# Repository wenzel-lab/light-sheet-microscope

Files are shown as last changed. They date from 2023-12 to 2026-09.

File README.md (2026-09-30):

# CLAVE Microscope

## **CLAVE:**  Cube-based Light-sheet Apparatus for Versatile 3D-imaging Experiments

<p align="centre">
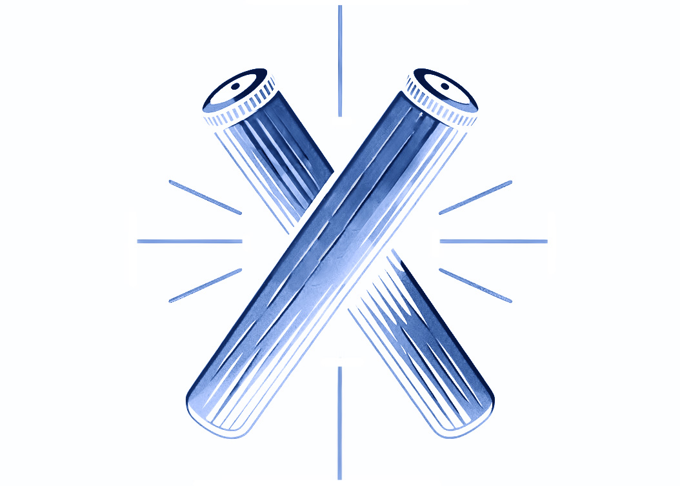
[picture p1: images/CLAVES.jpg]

</p>

Appropriate technology open source light sheet microscope design, for 3d imaging and high-throughput droplet cytometry. This is a modification of the OpenUC2 light sheet design - a project that can be explored by the [**website** ](https://openuc2.de/)and [**GitHub**](https://github.com/openUC2/UC2-GIT). This version has been developed as part of a [**crowd-funded project**](https://experiment.com/projects/developing-a-low-cost-high-sensitivity-solution-for-phage-viral-load-detection) on experiment.com by [Tobias Wenzel](https://librehub.github.io/people/tobias_wenzel/index.html) and [Benedict Diederich](https://openuc2.com/author/benedi/). In the Wenzel Lab, [Matías Hurtado](https://librehub.github.io/people/matias_hurtado/index.html) has also contributed to the design of several cubes, and the re-design of Inventor designs of [**UC2 cubes in OnShape.**](https://cad.onshape.com/documents/6ad90b1b9211810137d71b1d/w/b1b0cc05a0494bf4bc912f91/e/37e5ce9fc21af2a3e931ec46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)

### Work in progress:
A key aspect in terms of quality and cost of the light sheet microscope design is the laser-engine. With the open source laser we still dind't get an even-enough light sheet (until we improve a fiber vibration module), so we now oped for a second hand single 488nm colour coherent fiber laser that provides a very high quality gaussian beam. With this laser, the light sheet works great. We are also still in the process of trying alternative objectives and cameras, as well as finalising the sample holder and testing reference samples.

# Build your own:

<p align="centre">
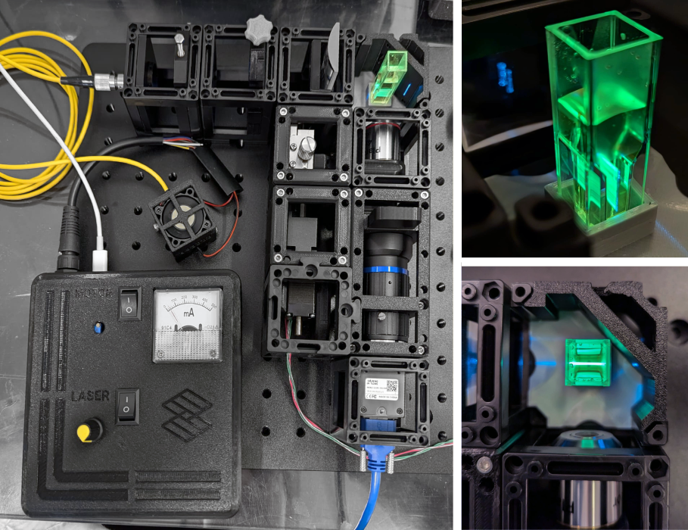
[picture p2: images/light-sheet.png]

</p>

<p align="centre">
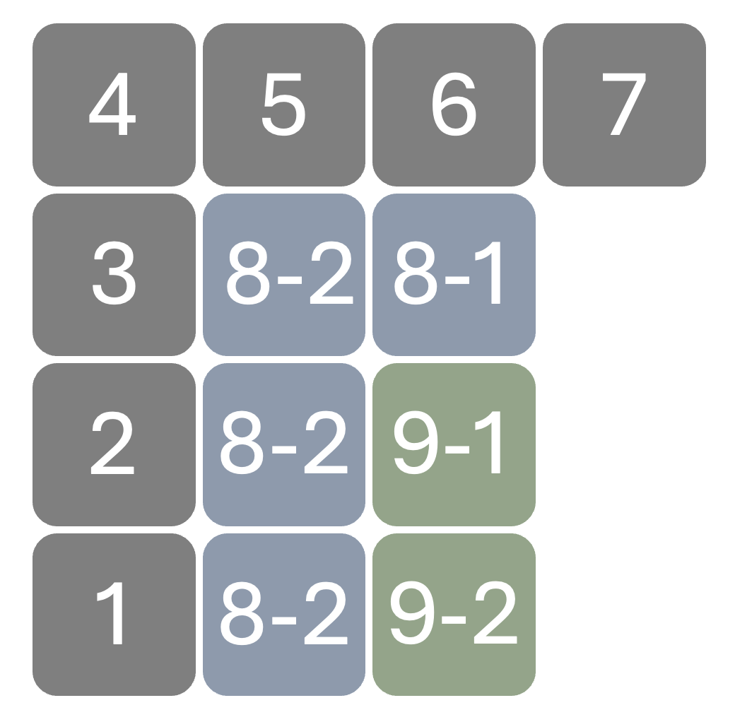
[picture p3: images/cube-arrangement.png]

</p>

<p align="centre">
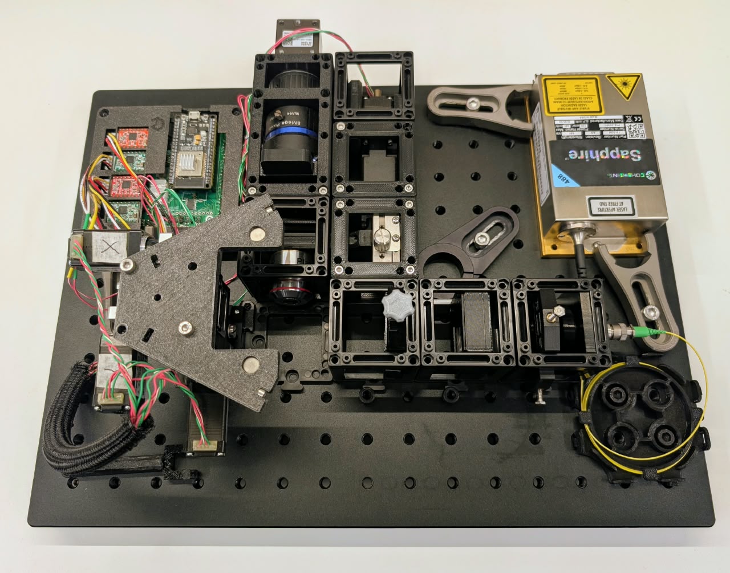
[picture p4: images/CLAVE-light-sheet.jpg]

</p>

## Navigation:

 * [Parts Gallery](gallery.md)

* [Prepare the pieces](Prepare.md)

* [Build your UC2](UC2files.md)

---

## Follow us:

  * [Twitter](https://twitter.com/WenzelLab), 
 * [YouTube](https://www.youtube.com/@librehub>), 
  * [LinkedIn](https://www.linkedin.com/company/92802424), 
*   [Instagram](https://www.instagram.com/wenzellab/), 
 *  [Printables](https://www.printables.com/@WenzelLab/models) &  [Thingiverse](https://www.thingiverse.com/libre-hub/designs)
* [LIBREhub website](https://librehub.github.io/),  
* [IIBM website](https://ingenieriabiologicaymedica.uc.cl/en/people/faculty/821-tobias-wenzel)

## Contribute:
This is an open project in the Wenzel Lab in Santiago, Chile. If you have any suggestions to improve it or add  additional functions make a pull-request or [open an issue](https://github.com/wenzel-lab/light-sheet-microscope/issues/new). For interactions in our team and with the community applies the [GOSH Code of Conduct](https://openhardware.science/gosh-2017/gosh-code-of-conduct/).

## License:
[CERN OHL 2W.](https://github.com/wenzel-lab/light-sheet-microscope/blob/main/LICENSE) This project is Open Source Hardware - please acknowledge us when using the hardware or sharing modifications.

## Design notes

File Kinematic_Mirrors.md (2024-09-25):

#Kinematic Mounts

Cube insert

{{BOM}}

[M3x20mm screw]: parts/mech/M3-20.md "{cat:mechanic}"
[M3 nut]: parts/mech/nuts.md "{cat:mechanic}"
[2.5mm Ball-end Allen key]: parts/tools/2.5mmBallEndAllenKey.md "{cat:tool}"
[Heat insert]: parts/mech/Hinsert.md "{cat:mechanic}"
[Round-Magnets]: parts/mech/magnets.md "{cat: mechanic}"

[Soldering iron]: parts/tools/soldiron.md "{cat:tool}"
[Tweezers]: parts/tools/tweezers.md "{cat:tool}"

[Knob]: models/Kinematic_Mirrors/Knob.stl "{previewpage}"
[Side-Kinematic-Mount-LIBREhub]: models/Kinematic_Mirrors/Side-Kinematic-Mount-LIBREhub.stl "{previewpage}"

[Diagonal-Kinematic-Mount-LIBREhub]:models/Kinematic_Mirrors/Diagonal-Kinematic-Mount-LIBREhub.stl "{previewpage}"
[Diagonal-Mirror-Surface-LIBREhub]:models/Kinematic_Mirrors/Diagonal-Mirror-Surface-LIBREhub.stl "{previewpage}"
[Side-Mirror-Surface-LIBREhub]:models/Kinematic_Mirrors/Side-Mirror-Surface-LIBREhub.stl "{previewpage}"

When using lasers, refractive elements for the beams are essential, even more the ones that can help control how and where exactly the light goes. In these models, the mirror can be calibrated from 3 knobs, 2 gold ones to move and a black one that is to be static

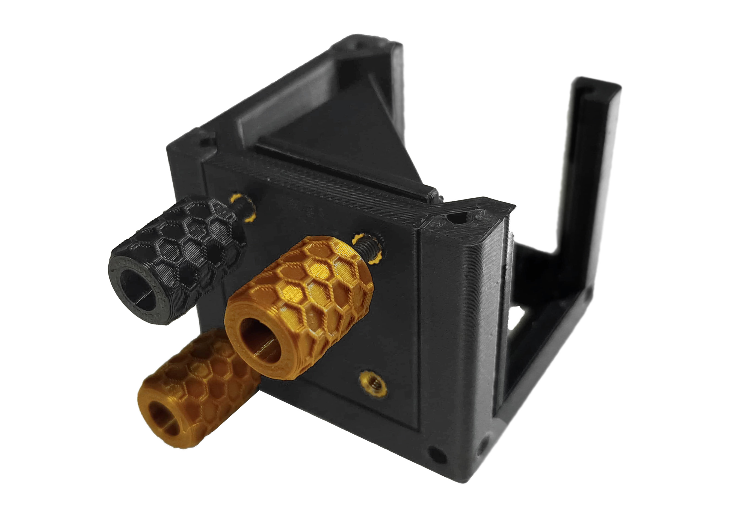
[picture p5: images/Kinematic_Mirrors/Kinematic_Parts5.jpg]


For this controlling system, we have two options depending on the user's needs.

- ## Diagonal Mirror:

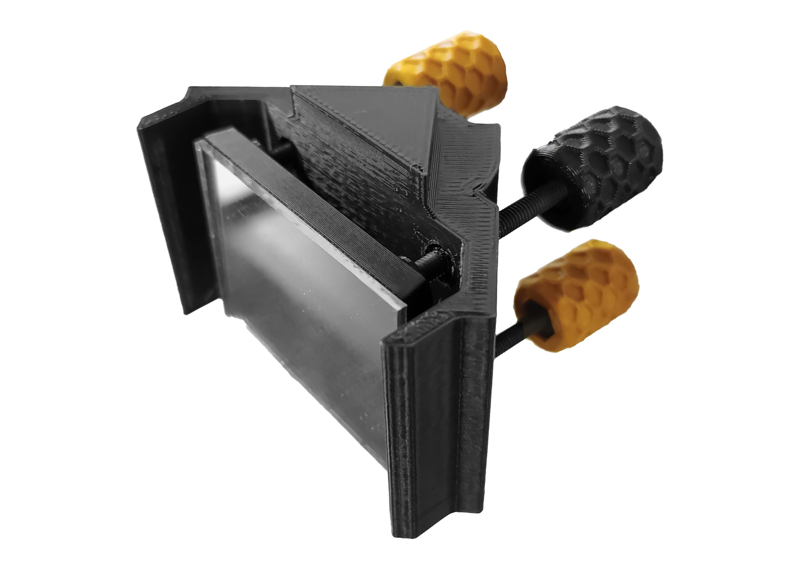
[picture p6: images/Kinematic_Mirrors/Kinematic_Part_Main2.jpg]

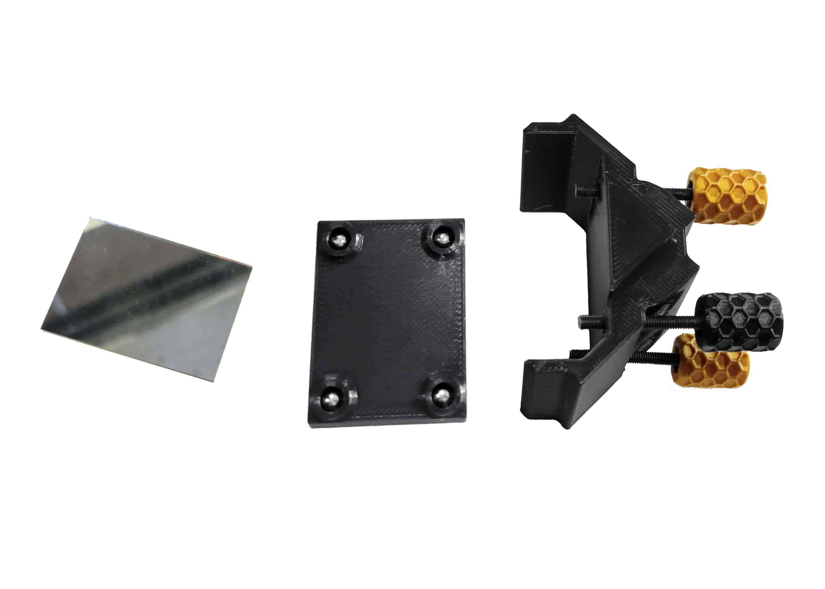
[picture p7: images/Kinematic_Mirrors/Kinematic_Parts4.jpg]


- ## Side Mirror:

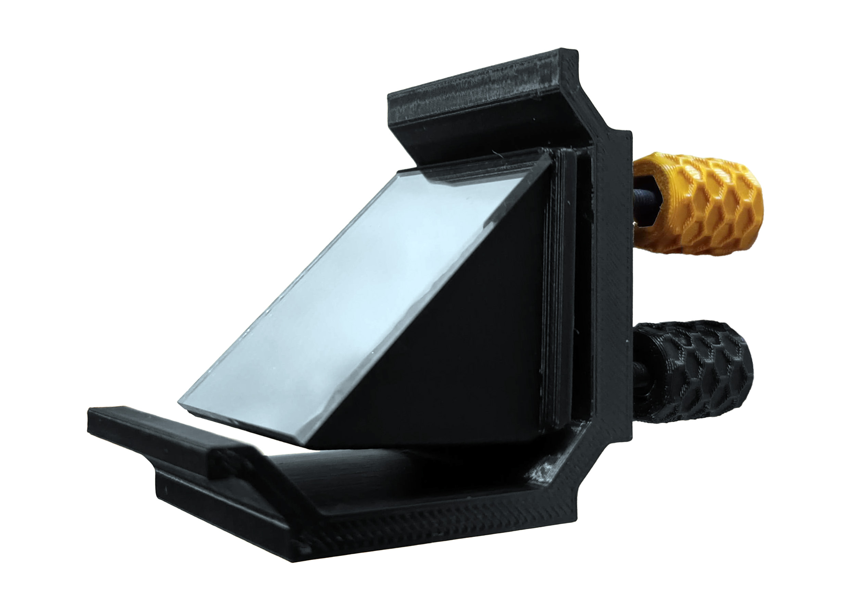
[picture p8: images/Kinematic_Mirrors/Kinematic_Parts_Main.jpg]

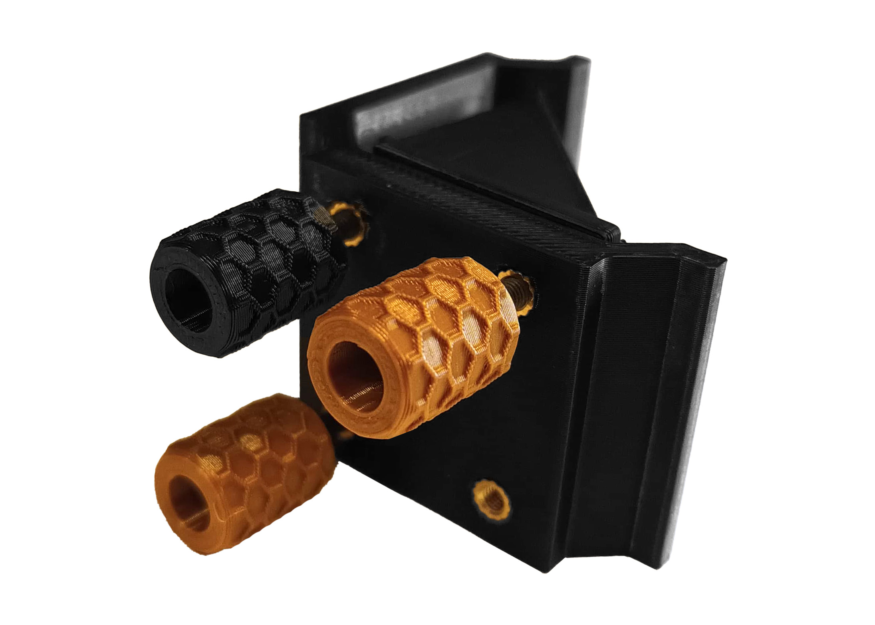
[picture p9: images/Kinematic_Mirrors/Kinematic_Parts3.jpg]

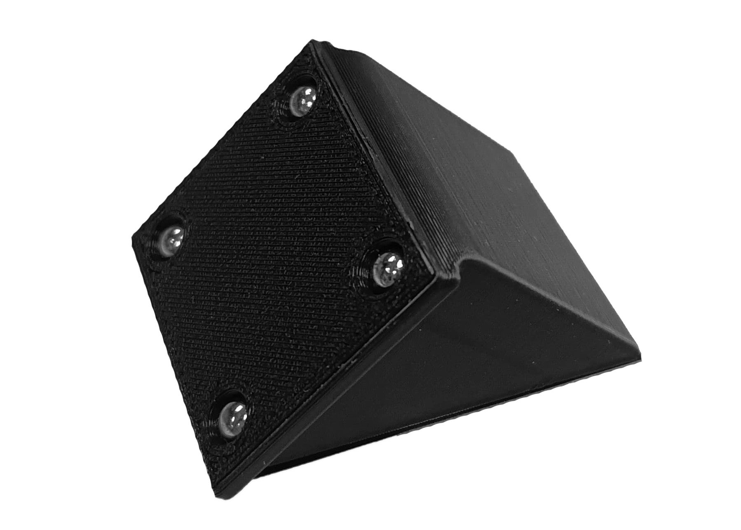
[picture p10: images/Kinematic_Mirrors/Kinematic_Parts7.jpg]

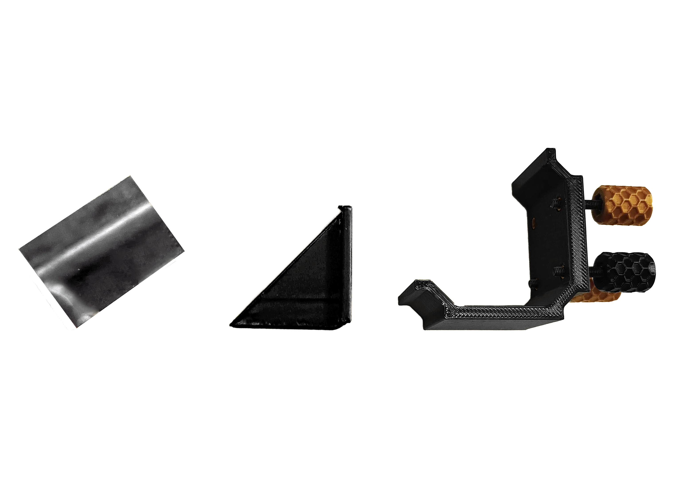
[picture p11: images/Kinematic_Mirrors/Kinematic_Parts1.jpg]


---

# Assemble the kinematic mounts:

## Knobs:{pagestep}

Place the [nut][M3 nut]{qty: 3} into the [knob][Knob]{qty: 3, cat:printedpart} and insert the [screw][M3x20mm screw]{qty: 3} tightly using the [Allen Key][2.5mm Ball-end Allen key]{qty:1}:



>? Please ensure that your screws are magnetic, as non-magnetic screws will not function properly with the magnets.

## Heat set inserts:{pagestep}

Use the [Soldering iron]{qty: 1} to place the [heat inserts][Heat insert]{qty: 3} into the [diagonal kinematic mount][Diagonal-Kinematic-Mount-LIBREhub]{qty: 1, cat:printedpart} or the [side kinematic mount][Side-Kinematic-Mount-LIBREhub]{qty: 1, cat:printedpart}, depending on the model you need.

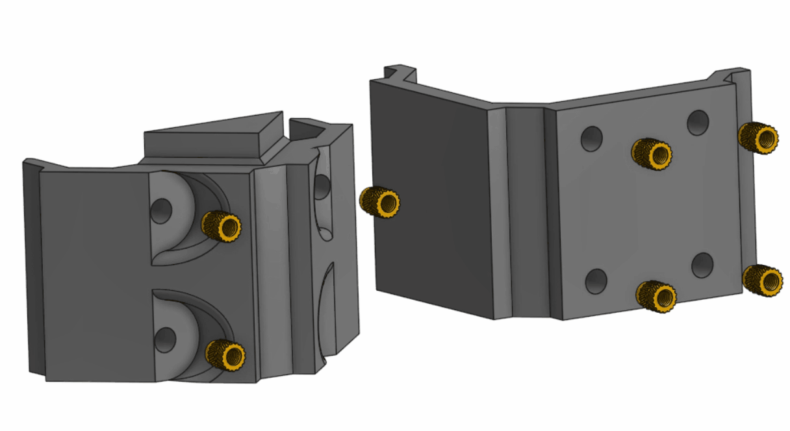
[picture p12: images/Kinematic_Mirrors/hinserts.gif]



## Place the magnets:{pagestep}

Place the [Round-Magnets]{qty: 4} in the [Diagonal-Mirror-Surface][Diagonal-Mirror-Surface-LIBREhub]{qty: 1, cat:printedpart} holes and press the flat side surface against the table to ensure that the surface stays completely flat. If you want to mount them for the [side kinematic mount][Side-Kinematic-Mount-LIBREhub], follow the same steps on the [Side-Mirror-Surface][Side-Mirror-Surface-LIBREhub]{qty: 1, cat:printedpart} but press the magnets into the piece and against the table so all the balls reach the opposite surface.

>! **Caution** 
>! The mirror surface must be flat so the mirror itself can be mounted

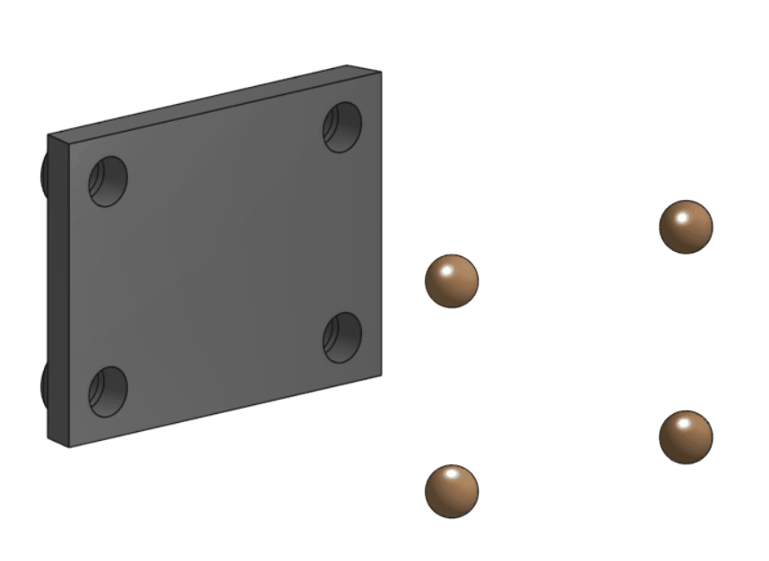
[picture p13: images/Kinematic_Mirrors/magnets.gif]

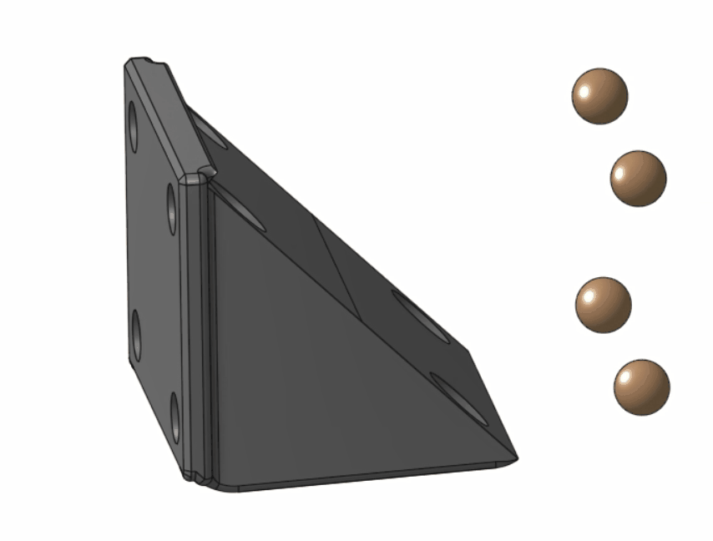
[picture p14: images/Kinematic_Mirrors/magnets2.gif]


## Mount the knobs:{pagestep}

Be sure to leave them all at the same approximate distance so they are easier to use later.



## Mount the Mirror:{pagestep}

1. Add some double-sided tape to the unprotected side of the mirror, peel off the plastic, and add it to the flat surface of the [Diagonal-Mirror-Surface][Diagonal-Mirror-Surface-LIBREhub]

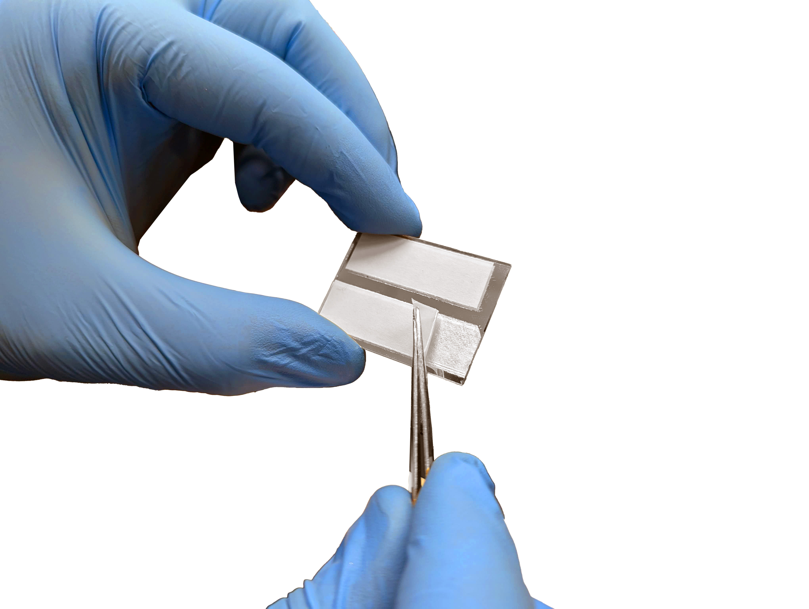
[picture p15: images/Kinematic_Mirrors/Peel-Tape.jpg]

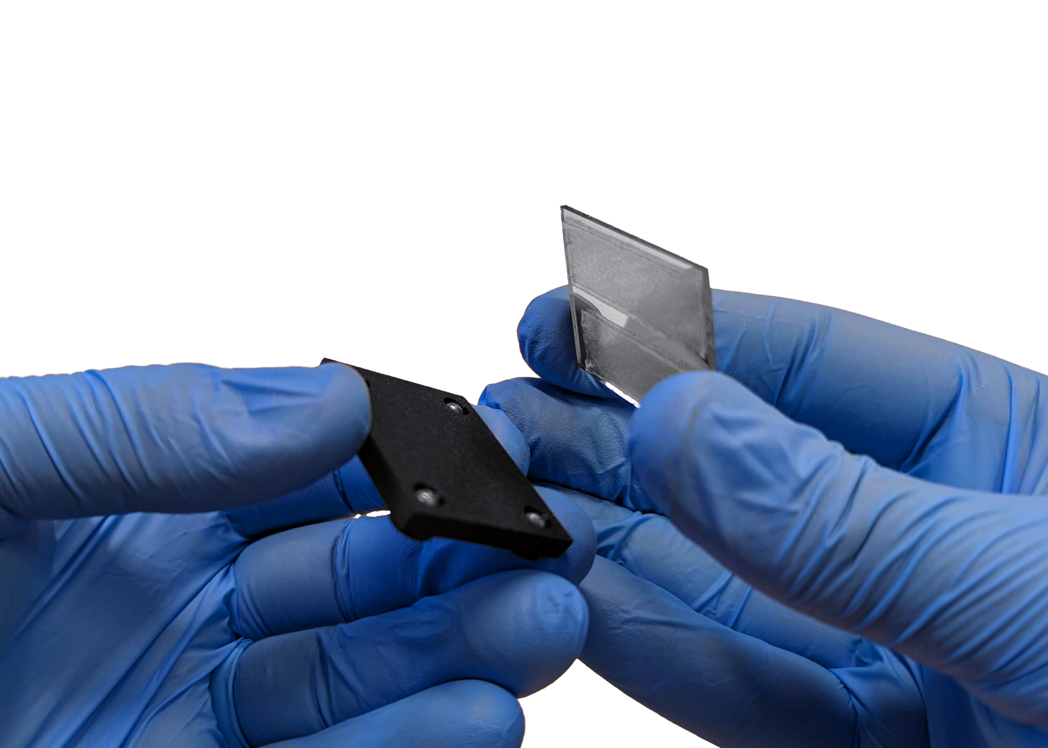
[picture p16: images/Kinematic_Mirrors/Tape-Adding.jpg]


2. Once added, peel off the protective plastic from the mirror with the [tweezers][Tweezers]{qty:1}

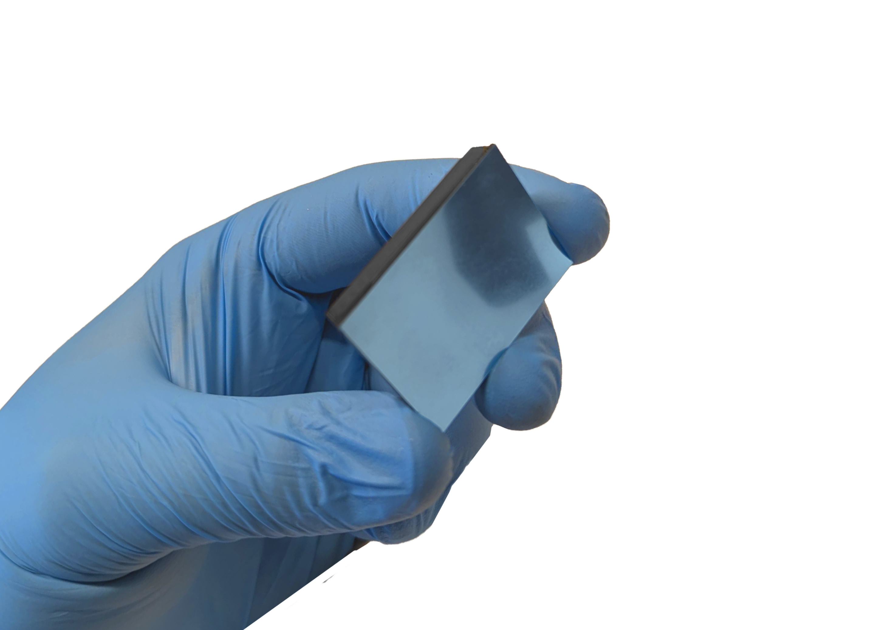
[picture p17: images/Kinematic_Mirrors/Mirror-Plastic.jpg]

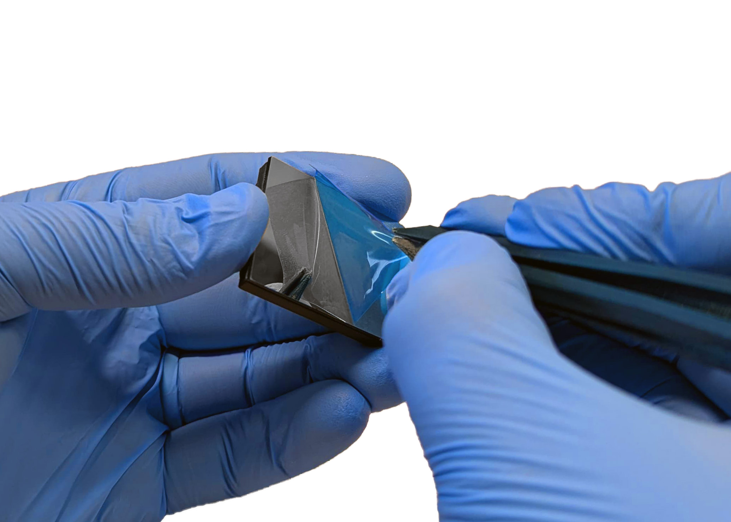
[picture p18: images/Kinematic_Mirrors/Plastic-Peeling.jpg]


3. Place the mirror holder onto the screw tips of the [kinematic mount][Diagonal-Kinematic-Mount-LIBREhub], the [magnets][Round-Magnets] will hold it in position.

>! **Caution** 
>! If the screw tips are not flat, the kinematic mirrors will not be as precise as they can be; therefore, it is necessary to [**sand them**](Sanding.md)

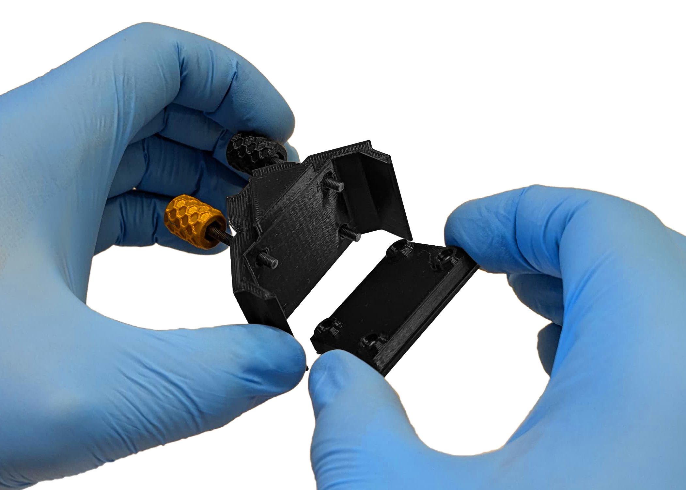
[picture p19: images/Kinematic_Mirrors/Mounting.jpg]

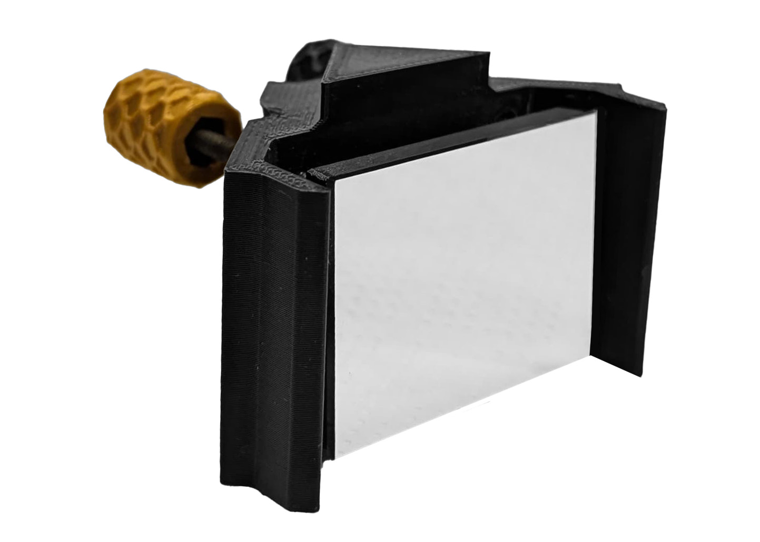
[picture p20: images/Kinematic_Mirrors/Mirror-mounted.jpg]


## Put it in a cube!:{pagestep}

Take one of your [UC2 cubes](UC2files.md) and place your assembled Kinematic Mirror in it. You can purchase the cube or 3D print it, either option works fine.

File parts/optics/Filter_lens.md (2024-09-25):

# Filter Lens
>!  This site is under construction.

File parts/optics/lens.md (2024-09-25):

# Lens

>!  This site is under construction.

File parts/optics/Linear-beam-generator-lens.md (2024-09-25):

---
PartData:
    Specs:
     Diameter: 9 mm
     Lens type: K9
     Material: Glass
     Degree: 5°
     _Supplier_: -[Aliexpress](www.aliexpress.com/item/1005005354365448.html)
---
# Linear Beam Generator Lens

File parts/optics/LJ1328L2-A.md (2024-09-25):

---
PartData:
    Specs:
        Length: 30 mm
        Width: 15 mm
        Thickness (center): 5.2 mm
        Radius: 10.3 mm
        Focal Length: 20.01 mm
        Antireflection Coating: 350-700 nm
        _Supplier_: -[Thorlabs](https://www.thorlabs.com/thorproduct.cfm?partnumber=LJ1328L2-A)
---
# LJ1328L2-A Lens

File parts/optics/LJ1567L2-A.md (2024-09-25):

---
PartData:
    Specs:
        Length: 60 mm
        Width: 30 mm
        Thickness (center): 5.2 mm
        Radius: 51.7 mm
        Focal Length: 100 mm
        Antireflection Coating: 350-700 nm
        _Supplier_: -[Thorlabs](https://www.thorlabs.com/thorproduct.cfm?partnumber=LJ1567L2-A)
---
# LJ1567L2-A Lens

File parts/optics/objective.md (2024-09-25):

# Objective
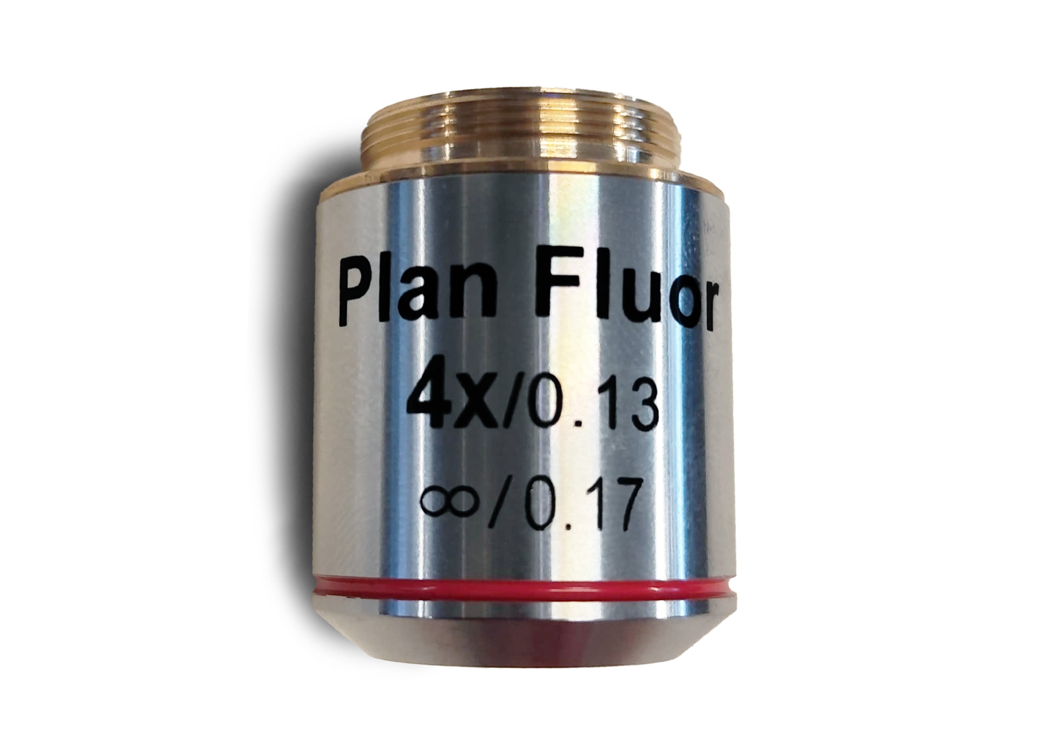
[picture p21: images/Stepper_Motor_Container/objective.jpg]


There are different types of objectives, depending on the experiment is which one you might need.

In this case, we are using a 4X/0.13 objective.

_Supplier_: [Thorlabs](https://www.thorlabs.com/thorproduct.cfm?partnumber=RMS4X-PF)

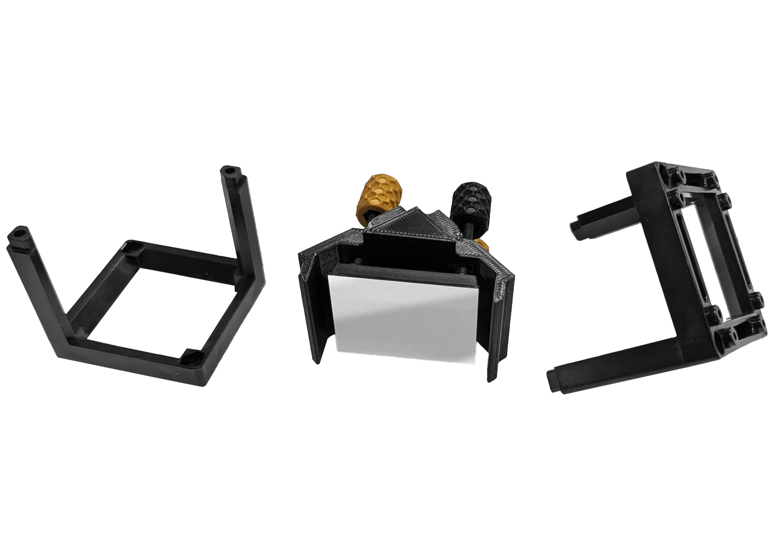
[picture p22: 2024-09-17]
images/Kinematic_Mirrors/Mirror-in-cube.jpg

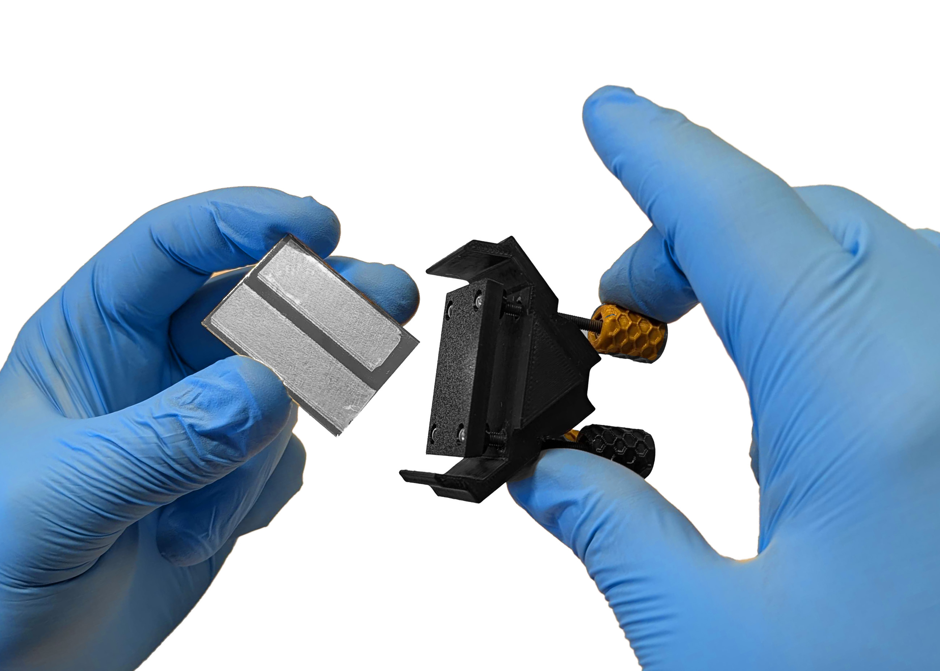
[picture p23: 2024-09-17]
images/Kinematic_Mirrors/Tape-Ready.jpg

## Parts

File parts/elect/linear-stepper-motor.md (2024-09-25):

#Stepper Motor



>!  This site is under construction.

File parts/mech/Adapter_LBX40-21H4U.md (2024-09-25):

# Adapter LBX40-21H4U

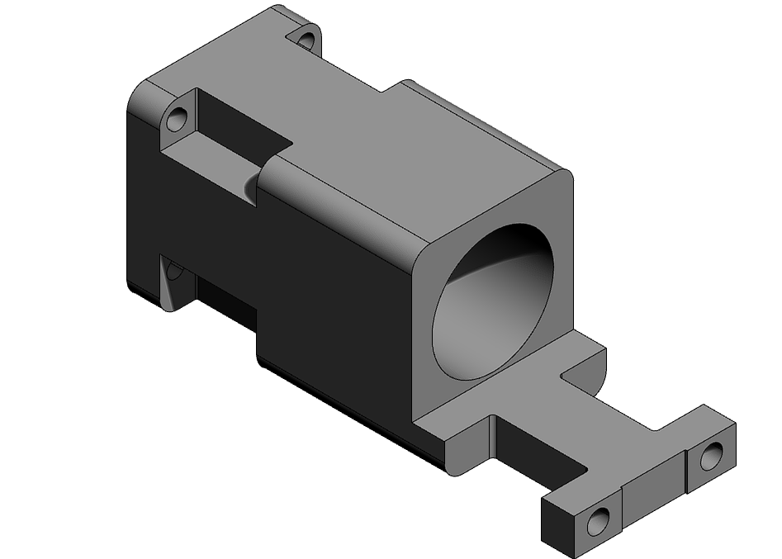
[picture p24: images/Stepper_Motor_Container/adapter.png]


You can dowload the STP file [here](../../models/Stepper_Motor_Container/adapter_LBX40_21H4U.stp), it is made to be CNC machinined.

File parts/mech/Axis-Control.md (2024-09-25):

# Axis Control

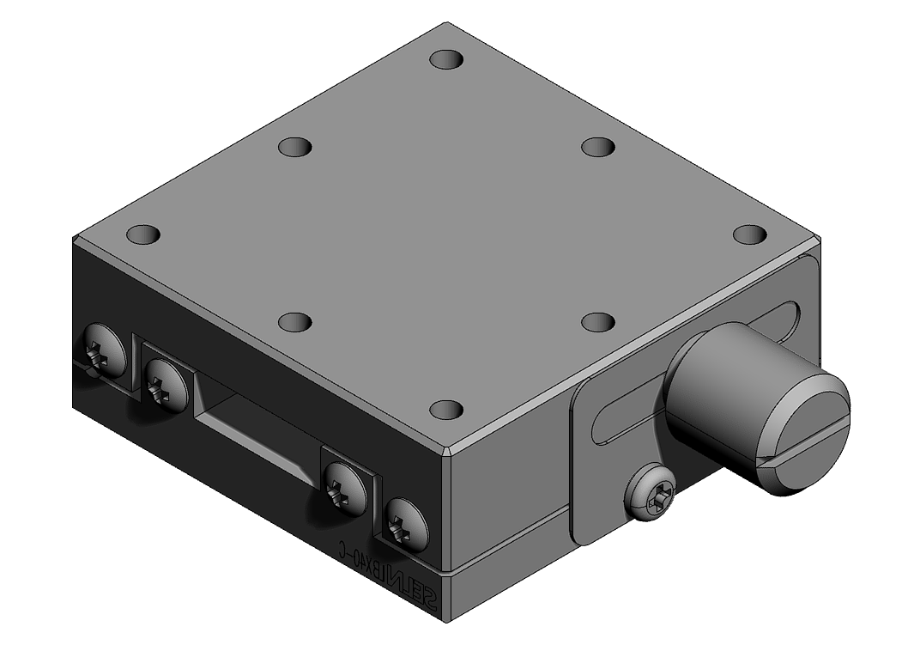
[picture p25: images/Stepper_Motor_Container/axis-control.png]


You can dowload the STP file [here](../../models/Stepper_Motor_Container/Axis-control.stp), it is made to be CNC machinined.

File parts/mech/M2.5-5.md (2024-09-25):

---
PartData:
    Specs:
        Type: M2.5
        Length: 5mm
        Material: Stainless steel
        Tool needed: HEX key
        Supplier:  -[Aliexpress](https://es.aliexpress.com/item/32810872544.html)

---
# Screw

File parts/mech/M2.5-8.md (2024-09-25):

---
PartData:
    Specs:
        Type: M2.5
        Length: 8 mm
        Material: Stainless steel
        Tool needed: HEX key
        Supplier:  -[Aliexpress](https://es.aliexpress.com/item/32810872544.html)
---
# Screw

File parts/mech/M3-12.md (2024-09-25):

---
PartData:
    Specs:
        Type: M3
        Length: 12mm
        Material: Stainless steel
        Tool needed: HEX key
        Supplier:  -[Aliexpress](https://es.aliexpress.com/item/32810872544.html)

---
# Screw

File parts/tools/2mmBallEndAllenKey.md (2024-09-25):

# 2 mm Ball-end Allen Key

Tool used to drive screws or bolts with hexagonal sockets. It has a metal shaft with a hexagonal cross-section. They come in different sizes for various applications.

It is important that the Allen key has a ball end:

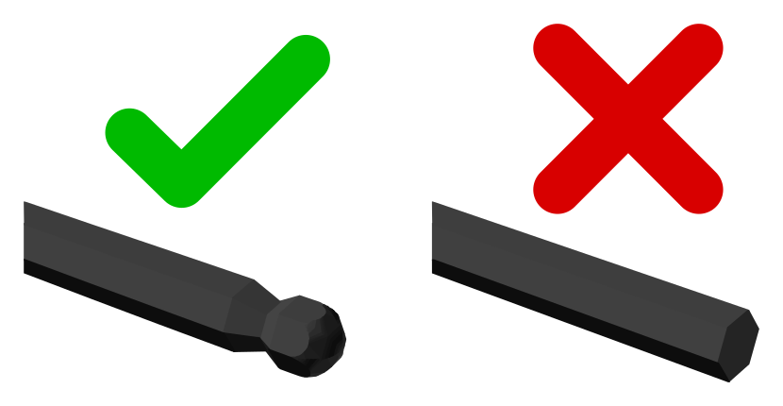
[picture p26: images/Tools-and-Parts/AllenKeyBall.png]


*Supplier:* [ferretería.cl](https://ferreteria.cl/ficha/5866/juego-de-llave-allen-larga-de-bola-metrico-9-pzs-tactix)

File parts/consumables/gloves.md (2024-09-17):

# Nitrile gloves

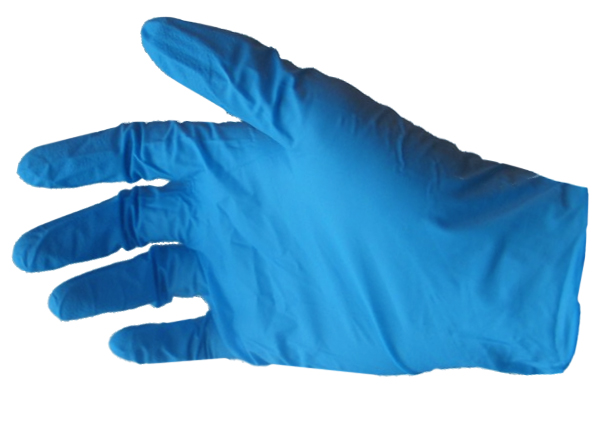
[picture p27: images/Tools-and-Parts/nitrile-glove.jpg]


They safeguard sensitive electronic components from contamination, oils, and static discharge.

These gloves prevent potential damage during assembly, repair, or handling of electronic devices.

*Supplier:* [bioquimica.cl](https://www.bioquimica.cl/guantes-de-nitrilo-sin-polvo-caja-100-un)

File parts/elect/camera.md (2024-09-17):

# High-Speed Camera

>!  This Site is under construction.

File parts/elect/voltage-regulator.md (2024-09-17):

# Voltage Regulator
It is used to control manually exactly how much electricity circulates. 



_Supplier:_ [AFEL](https://afel.cl/producto/regulador-de-voltaje-step-down-dc-dc-lm2596-con-voltimetro/)

This regulator has modifications documented [here](https://github.com/wenzel-lab/modular-microfluidics-workstation-controller)

>! In some models, the electronics of this can be exposed, be sure to cover them to avoid possible accidents.

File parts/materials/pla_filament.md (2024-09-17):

# PLA filament

The design has been tested using PLA filament only. PLA is the most common 3D printer filament. It is easy to use and has low part shrinkage. We have found that the lifetime of the parts is affected by the quality of the PLA filament, as such we recommend buying high quality filament and storing the filament in a dry sealed container before printing.

_Supplier:_ [Esun](https://www.esun3d.com/) or [Todo Toner](https://www.todotoner.cl/impresoras/impresoras-3d/filamentos/pla-plus-1kg-negro-esun)

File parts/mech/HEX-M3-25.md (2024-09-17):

---
PartData:
    Specs:
        Type: M3
        Length: 25mm
        Material: Stainless steel
        Tool needed: Spanner
        Supplier:  -[Aliexpress](https://aliexpress.com/item/32968601031.html)
---

# M3 HEX screw

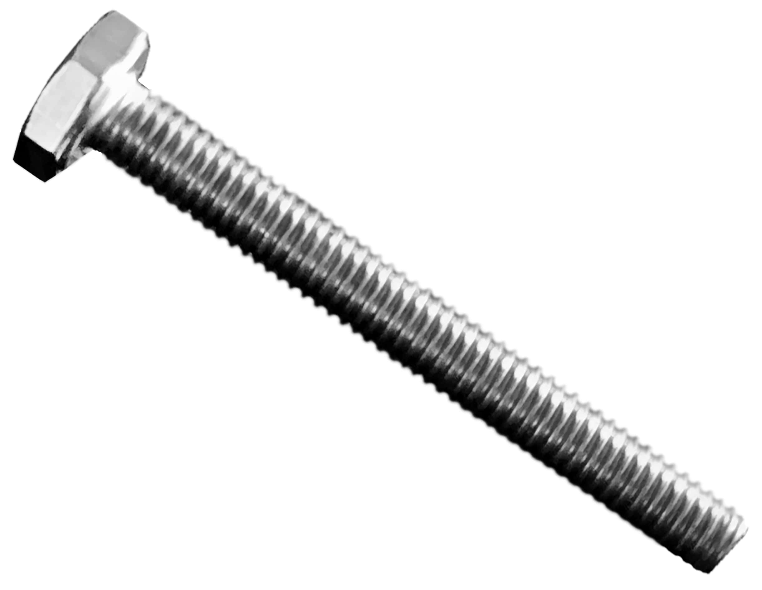
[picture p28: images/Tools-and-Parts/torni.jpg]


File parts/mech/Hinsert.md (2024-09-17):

---
PartData:
    Specs:
        Type: M3
        Diameter: 4mm aprox.
        Material: Brass
        Tool needed: Soldering iron
        Supplier: -[Aliexpress](https://es.aliexpress.com/item/1005005220632314.html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)

---
# Heat inserts

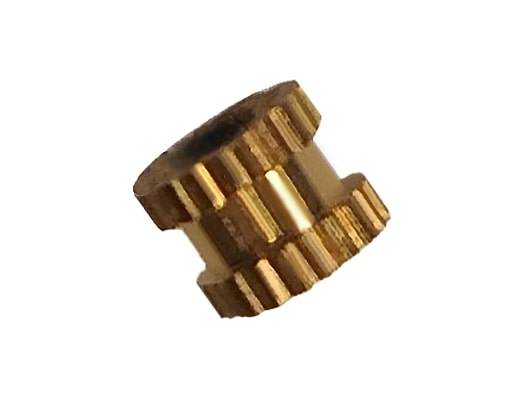
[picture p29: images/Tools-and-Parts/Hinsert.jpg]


Threaded insert used for creating secure connections in materials. Heat is applied to soften the material, allowing the insert to be pressed or screwed in. It provides a strong threaded connection in materials like plastic, acrylic and wood. Used in industries like electronics, automotive, and aerospace.

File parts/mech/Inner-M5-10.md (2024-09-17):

---
PartData:
    Specs:
        Type: M5
        Length: 10mm
        Material: Stainless steel
        Tool needed: HEX key
        Supplier:  -[Aliexpress](https://es.aliexpress.com/item/32810872544.html)
---
# Inner Screw

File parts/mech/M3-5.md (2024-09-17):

#screw

---
PartData:
    Specs:
        Type: M3
        Length: 5 mm
        Material: Stainless steel
        Tool needed: HEX key
        Supplier:  -[Aliexpress](https://es.aliexpress.com/item/32810872544.html)

---

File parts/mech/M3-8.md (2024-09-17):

---
PartData:
    Specs:
        Type: M3
        Length: 8mm
        Material: Stainless steel
        Tool needed: HEX key
        Supplier:  -[Aliexpress](https://es.aliexpress.com/item/32810872544.html)
---
# Screw

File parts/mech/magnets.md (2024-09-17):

---
PartData:
    Specs:
        Diameter: 5mm
        Supplier:  -[La casa del imán](https://www.lacasadeliman.cl/products/216-bolitas-magneticas)
---
# Round Magnets
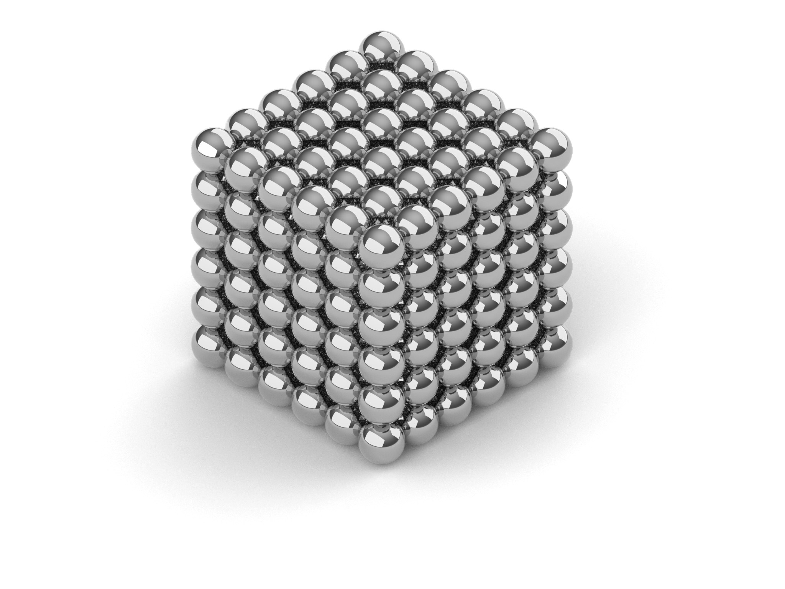
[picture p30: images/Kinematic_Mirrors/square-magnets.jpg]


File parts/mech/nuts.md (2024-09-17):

# Nut

Small hexagonal or square-shaped object with a threaded hole used to fasten objects together. It pairs with a screw.

*Supplier:* [Aliexpress](https://www.aliexpress.com/item/1005003780212966.html)

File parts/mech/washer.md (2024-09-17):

---
PartData:
    Specs:
        Type: M3
        Material: Stainless steel
        Supplier:  -[Pernos kim](https://pernos-kim.negocio.site/)

---
# Screw washer

* Small disk used with screws or bolts. It distributes the load and protects surfaces. It prevents damage and provides stability. Different materials and types are available for specific applications. It enhances the performance of the fastening system.

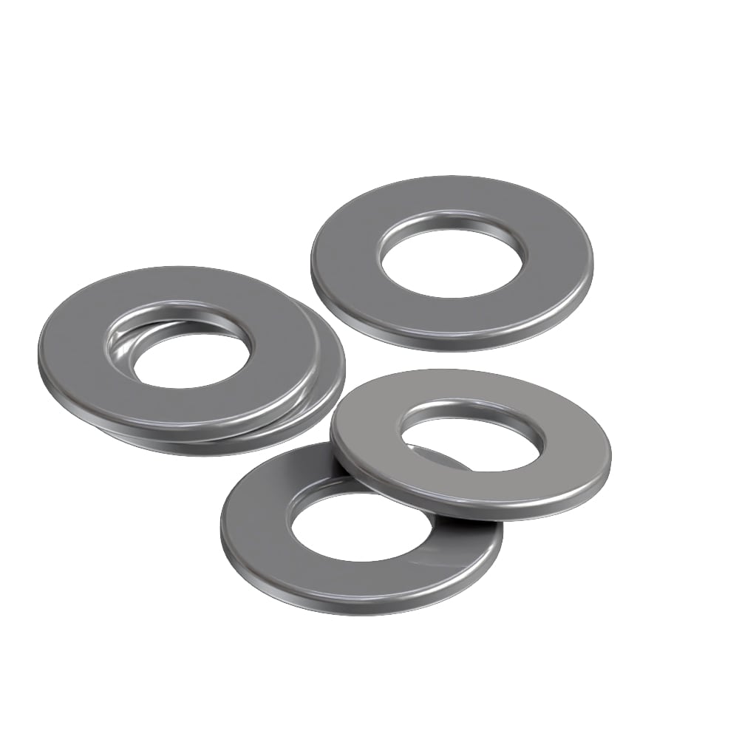
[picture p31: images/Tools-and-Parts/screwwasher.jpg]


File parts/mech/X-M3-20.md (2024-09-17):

---
PartData:
    Specs:
        Type: M3
        Length: 20 mm
        Material: Stainless steel
        Tool needed: screwdriver
        Supplier:  -[Aliexpress](https://es.aliexpress.com/item/32971605141.html)
---
# M3 X Screw



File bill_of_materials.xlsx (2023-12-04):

Category | Amount | Part | Shop | Price (€) | Comment | What we have | Quantity | URL/Source
External Parts | 1 | Cylindrical lens, comar | Thorolabs | 150 | f = 100mm H = 30 mm L = 32 mm | f = 8mm f = 50 mm f = 20 mm (2x) | 1 | Link (https://www.thorlabs.com/thorproduct.cfm?partnumber=LJ1567L1)
 | 1 | Camera, monochrome, CMOS | Daheng | 350 |  |  | 1 | Link (https://www.machinevisionkamera.de/USB3-Bildverarbeitungskamera-12.2MP-Monochrome-Sony-IMX226-MER2-1220-32U3M)
 | 1 | Focusing stage, micrometer, motorized (NEMA12) | China | 100 |  |  | 1 | Haoran
 | 1 | 10x objective, NA0.3, long-working distance | USA | 250 | 10x and NA 0.3 | 100x, NA1.25 100x NA1.4 20x NA0.5 12.5x NA? 10x NA0.25 is being used(yellow one) | 1 | Link (https://bolioptics.com/10x-infinity-corrected-plan-achromatic-microscope-objective-lens-bm05073332/)
 | 1 | XYZ stage, AliExpress, micrometer | China | 250 |  |  | 1 | Link (https://de.aliexpress.com/item/33013923564.html?gatewayAdapt=glo2deu)
 | 3 | Motor for stage | China | 80 |  |  | 3 | Link (https://eckstein-shop.de/PololuStepperMotorNEMA11Bipolar200StepsRev28C39732mm38V067APhase)
 | 1 | Tube lens | China | 200 | f = 100mm F3.5 | Lots of lenses does not have specifications | 1 | Link (https://www.berrybase.de/100mm-teleobjektiv-c-mount)
 | 1 | Fiber laser | China | 200 | ?? | https://www.thorlabs.com/thorproduct.cfm?partnumber=P1-460A-FC-5 This is the one that we have, dont know if it works | 1 | Haoran
 | 1 | Mirror | PGI | 5 | Simple small mirror | We have some thorlabs mirrors | 1 | Link (https://pgi-shop.de/vorderflaechen-glasspiegel-30-0-x-40-0-mm/)
 | 1 | 4x objective lens finite | China | 10 | 4x | 4x (x2) | 1 | Haoran
 | 1 | Fiber Collimator | China | 100 |  | Could we build it with lenses? | 1 | Haoran
 | 14 | Baseplates | openUC2 | 3 |  |  | 14
 | 8 | Cubes | openUC2 | 5 |  |  | 10
 | 1 | Solid baseplate (aluminium) | openUC2 | - |  |  | 1
 | 1 | Excitation filter (Thorlabs) | Thorolabs | 120 | 500 nm cut-on | 500 nm long pass (CORION) | 1 | Link (https://www.thorlabs.com/thorproduct.cfm?partnumber=FELH0500)
Inserts (3D printable?) | 1 | Fiber Collimator Mount | openUC2 | 5 |  |  | 1
 | 1 | Cylindrical Lens Mount | openUC2 | 5 |  |  | 1
 | 1 | 45° Mirror Mount (kinematic) | openUC2 | 25 |  |  | 1
 | 1 | RMS Lens Mount | openUC2 | 5 |  |  | 1
 | 1 | Sample mount (printed) | openUC2 | 30 |  |  | 1
 | 1 | Base for XYZ Stage | openUC2 | 2 |  |  | 1
 | 1 | Sample mount for XYZ Stage | openUC2 | 15 |  |  | 1
 | 1 | Holder for Z-stage motorized | openuc2 | 30 |  |  | 1
 | 1 | Holder for Tubelens | openUC2 | 10 |  |  | 1
 | 1 | Holder for UC2 Electronics | openUC2 | 30 |  |  | 1
Electronics | 1 | Electronics, Powersupply, Stepper driver | openUC2 | 100 |  |  | 1
 | 2 | USB cables (camera, micro) | Germany | 60 |  |  | 2
 | 1 | Playstation Controller | Germany | 50 |  |  | 1
 | 1 | Box + Foam insert | openUC2 | 100 |  |  | 1 | Link (https://www.contorion.de/p/stier-universal-outdoor-koffer-flugtauglich-lxbxh-418x317x151-mm-86520627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)
Labour & Shipping | - | Labour + Shipping | - | 500 |  |  | 1

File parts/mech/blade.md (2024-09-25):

# Razor Blades
>!  This site is under construction.

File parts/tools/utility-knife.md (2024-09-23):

# Utility knife / Box cutter

Any standard utility knife should work for simple jobs like removing a brim.

A retractable or fixed-blade utility knife should work. This is probably safer than a scalpel, but should still be used with caution! A Stanley Titan fixed blade knife is a high-quality option with replaceable blades that are fixed rather than retractable.



*Supplier:* [Sodimac](https://www.sodimac.cl/sodimac-cl/articulo/110284473/Cuchillo-cartonero-metal/110284475)

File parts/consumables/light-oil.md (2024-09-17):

# Light oil

A component that lubricates the mechanism to make it work more smoothly.



*Supplier:* [Sodimac](https://www.sodimac.cl/sodimac-cl/articulo/110368264/Lubricante-multiuso-para-auto-89-ml/110368269)

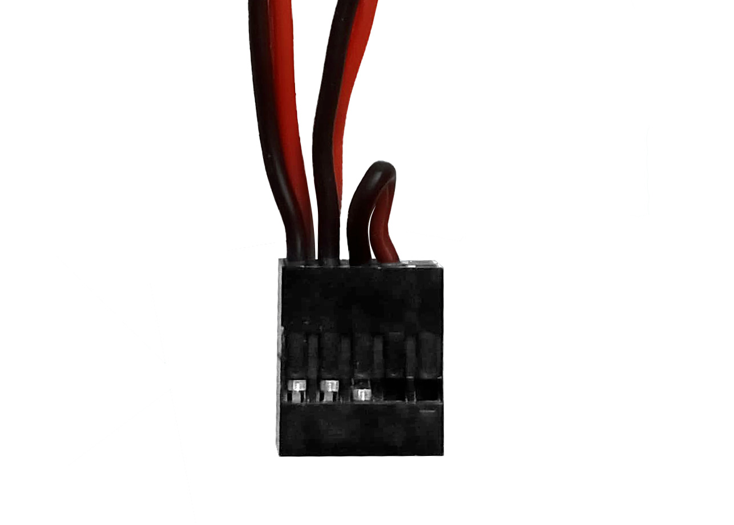
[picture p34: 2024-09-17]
images/Tools-and-Parts/strobe_cables.jpg

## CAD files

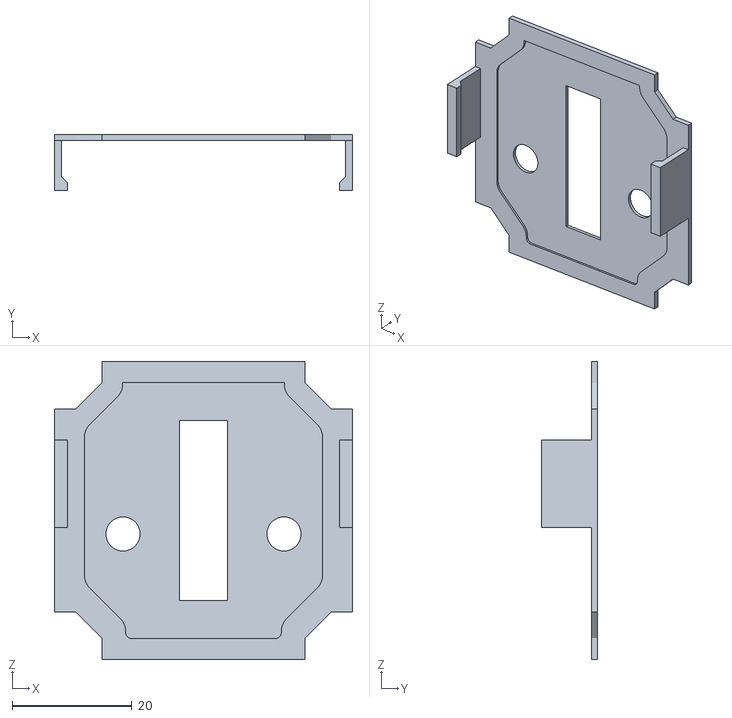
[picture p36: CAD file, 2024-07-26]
models/Adjustable_slit/Compliant_slit_insert_V2-cap_layer.stl
49.8 x 9.40 x 49.8

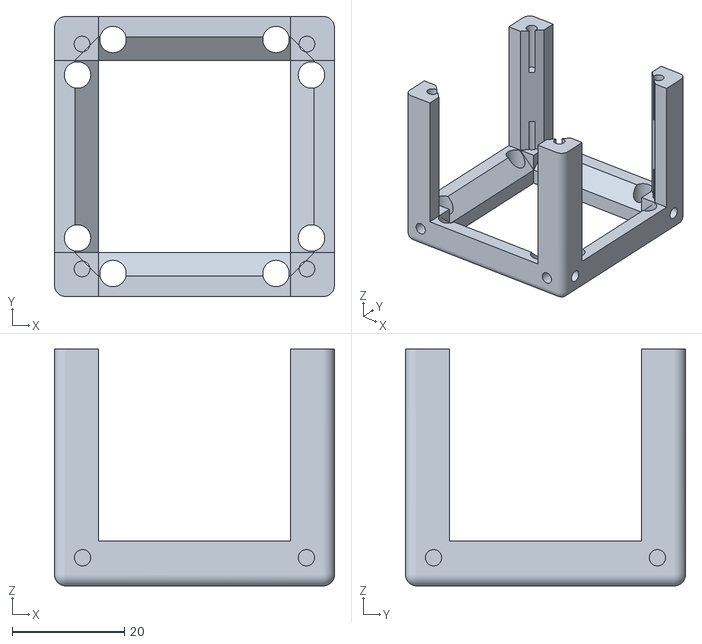
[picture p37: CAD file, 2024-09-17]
models/Base_Cube/Single_Base_Cube.stl
49.8 x 49.8 x 42.1

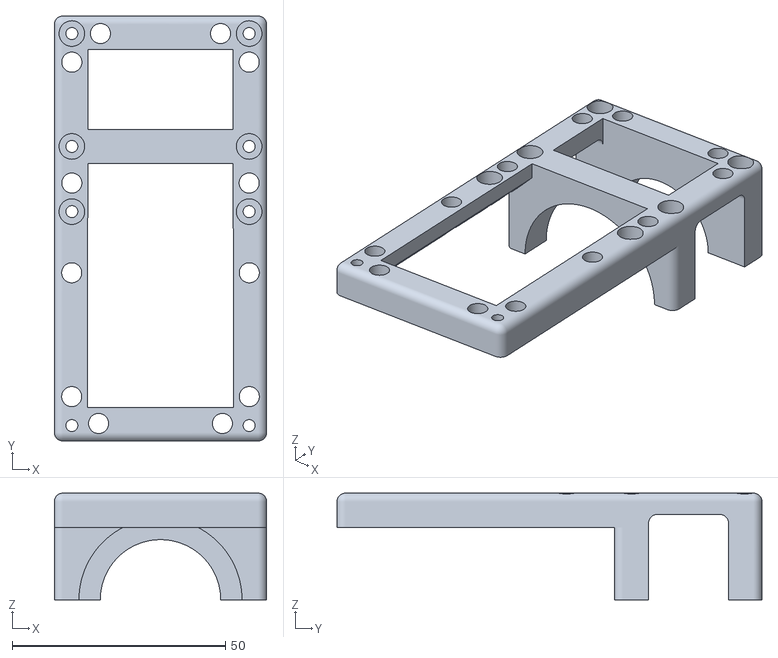
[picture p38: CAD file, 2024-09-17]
models/Double_Cube_Lens_Holder/LightSheet_Remake-Double_Cube_Lens_Holder_B.stl
49.8 x 99.6 x 25.0

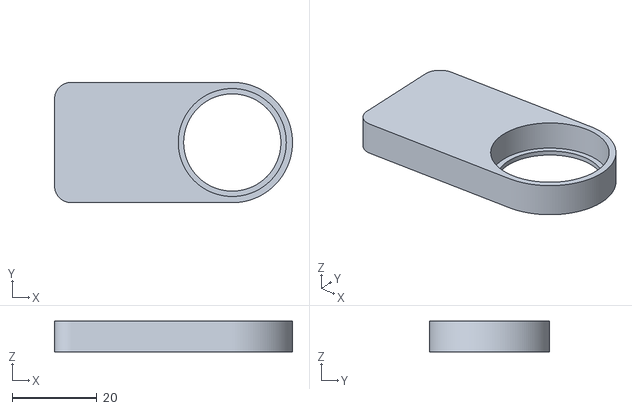
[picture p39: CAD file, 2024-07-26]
models/Filter_Holder/Filter-Slide-25-mm.stl
56.3 x 28.5 x 7.25

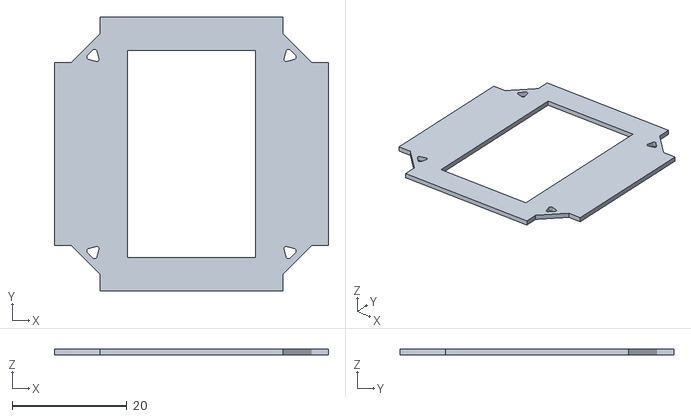
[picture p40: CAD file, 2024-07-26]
models/Flexure_cylindrical_lens_holder/Flexure_cylindrical_lens_holder-cyl-lens-holder-lid.stl
47.8 x 47.8 x 1.00

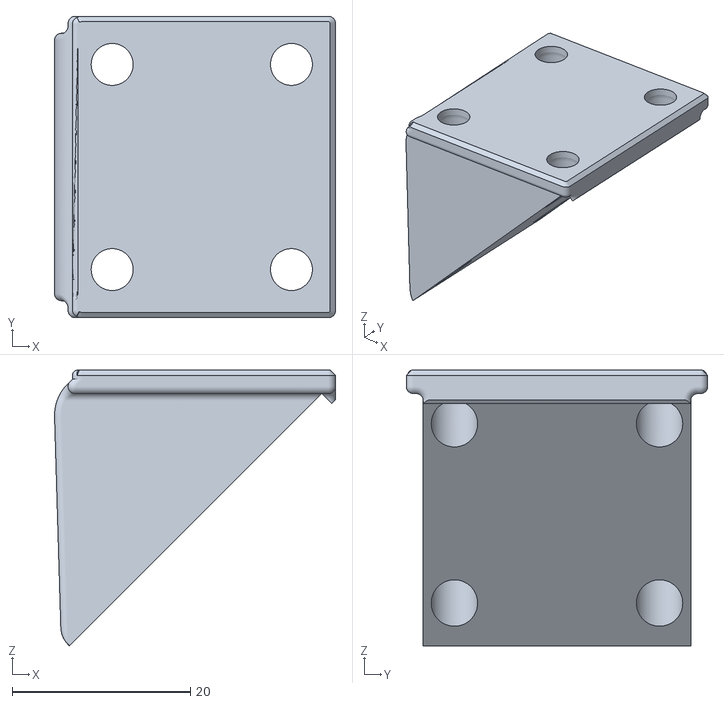
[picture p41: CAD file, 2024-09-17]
models/Kinematic_Mirrors/Side-Mirror-Surface-LIBREhub.stl
31.5 x 33.8 x 30.9

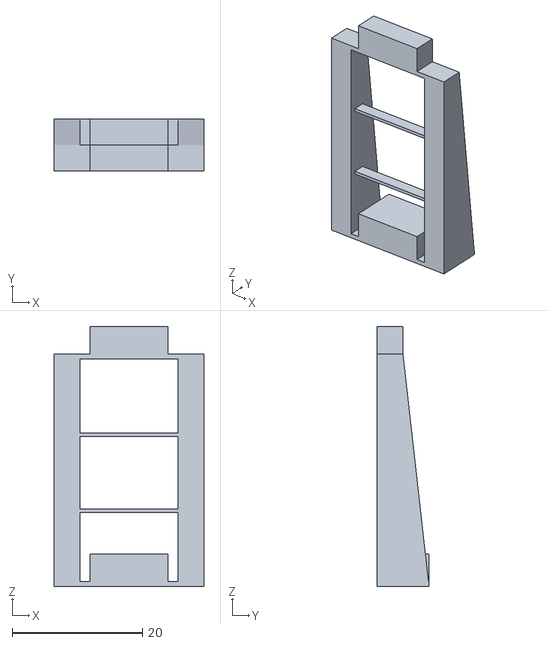
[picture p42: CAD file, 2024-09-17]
models/leg_test.stl
23.0 x 8.00 x 40.0

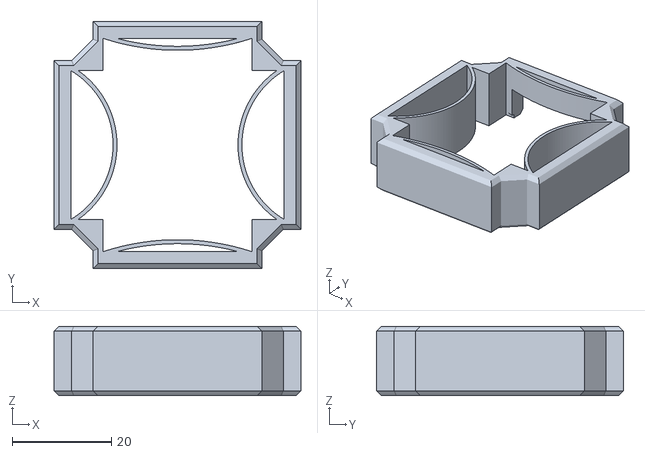
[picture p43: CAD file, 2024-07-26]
models/Lens_Holder/Flexure_cylindrical_lens_holder-cyl-lens-holder-extra-tall.stl
49.8 x 49.8 x 14.0

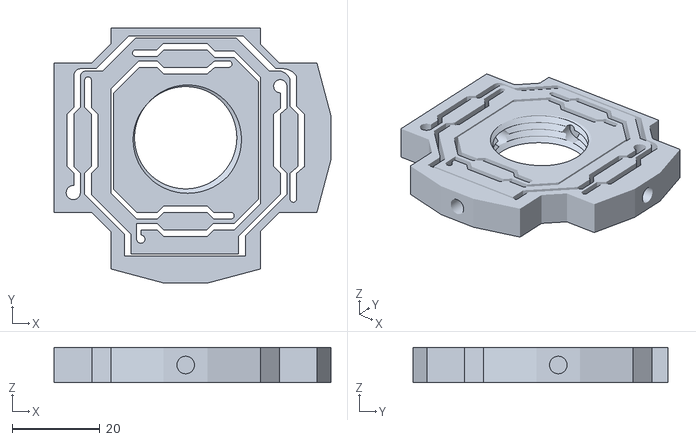
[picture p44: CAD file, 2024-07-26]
models/Power-Lense-XY-aligner/Power-Lens-XY-aligner-base.stl
63.1 x 58.1 x 8.00

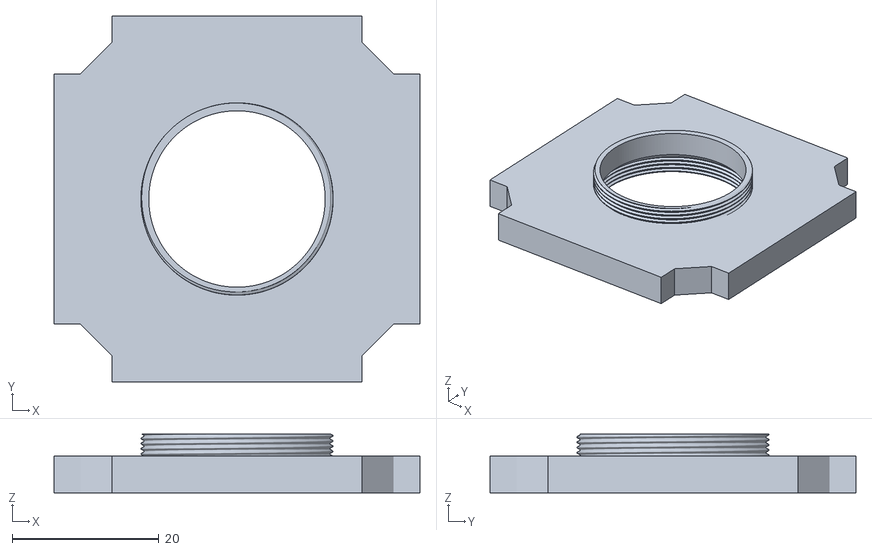
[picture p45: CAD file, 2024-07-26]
models/SM1_holder/UC2-SM2_adaptor - Insert-with-SM1-double-thread.stl
49.8 x 49.8 x 8.00

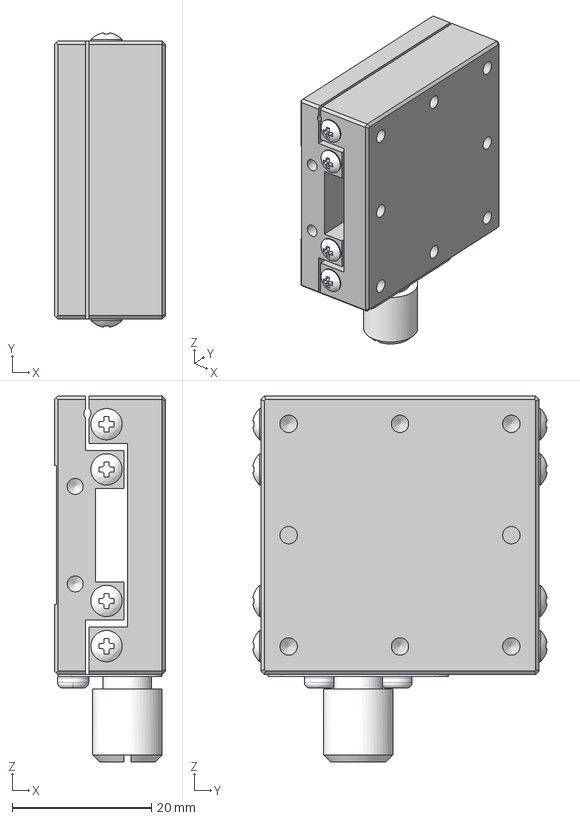
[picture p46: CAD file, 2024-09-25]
models/Stepper_Motor_Container/Axis-control.stp
16.0 x 42.3 x 52.6 mm

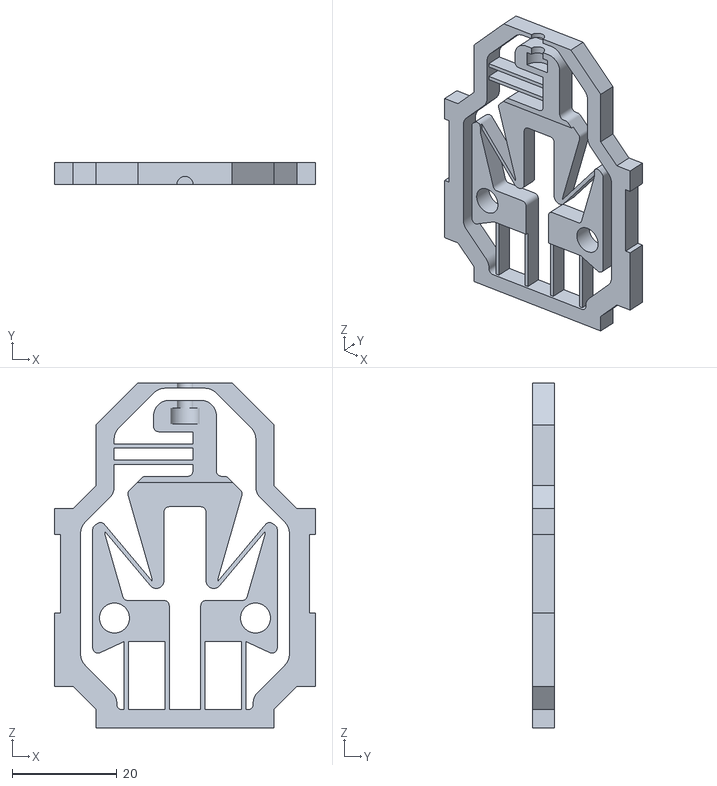
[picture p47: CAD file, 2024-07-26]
models/Adjustable_slit/Compliant_slit_insert_V2-flex_layer2.stl
49.8 x 4.20 x 65.8

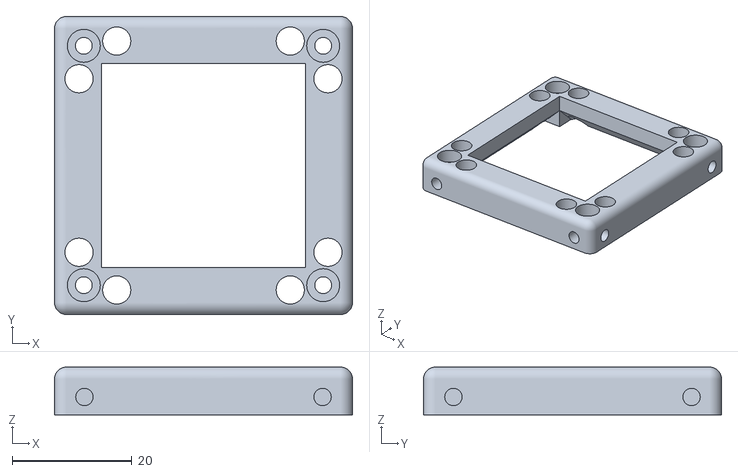
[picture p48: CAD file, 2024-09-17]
models/Base_Cube/Single_Top_Cube.stl
49.8 x 49.8 x 8.00

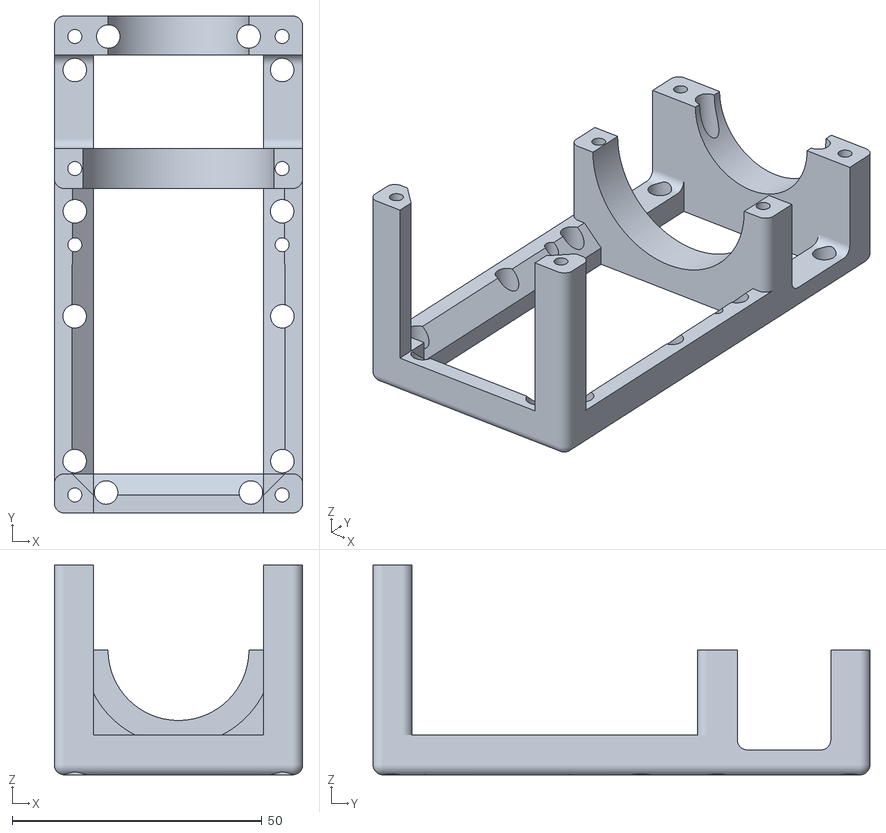
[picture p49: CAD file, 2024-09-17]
models/Double_Cube_Lens_Holder/LightSheet_Remake-Double_Cube_Lens_Holder_A.stl
49.8 x 99.6 x 42.0

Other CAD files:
models/Filter_Holder/Holder-Filter-Slide-25-mm.stl
models/Kinematic_Mirrors/Diagonal-Kinematic-Mount-LIBREhub.stl
models/Lens_Holder/Flexure_cylindrical_lens_holder-cyl-lens-holder-flex.stl
models/Adjustable_slit/Compliant_slit_insert_V2-flex_layer1.stl
models/Base_Cube/Base_puzzle.stl
models/Flexure_cylindrical_lens_holder/Flexure_cylindrical_lens_holder-cyl-lens-holder-flex.stl
models/Kinematic_Mirrors/Diagonal-Mirror-Surface-LIBREhub.stl
models/Kinematic_Mirrors/Knob.stl
models/Kinematic_Mirrors/Side-Kinematic-Mount-LIBREhub.stl
models/Power-Lense-XY-aligner/Power-Lens-XY-aligner-A-Adapter.stl
models/SM1_holder/UC2-SM2_adaptor - 5mm-pinhole-SM1.stl
models/Stepper_Motor_Container/LightSheet_Remake-Inner_Motor_Holder.stl
models/Stepper_Motor_Container/LightSheet_Remake-New_Axis_Cube.stl
models/Stepper_Motor_Container/LightSheet_Remake-New_Axis_Cube_Top.stl
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

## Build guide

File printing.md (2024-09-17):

# Print the plastic parts

{{BOM}}

[PLA filament]: parts/materials/pla_filament.md "{cat:material}"
[Black PLA filament]: parts/materials/black_pla_filament.md "{cat:material}"
[RepRap-style printer]: parts/tools/rep-rap.md "{cat:tool}"
[Precision wire cutter]: parts/tools/precision-wire-cutters.md "{cat:tool}"
[Utility knife]: parts/tools/utility-knife.md "{cat:tool}"
[leg test]:models/leg_test.stl "{previewpage}"

## Set your printer settings {pagestep}

Almost all parts can be printed out of [PLA filament] on most [RepRap-style printers][RepRap-style printer]{qty:1}.

We recommend the following printer settings:

|Setting |Value |
|--- |-- |
|Material |PLA |
|Material Temperature |Recommended by the PLA brand|
|Layer height |0.2mm or less  |
|Infill |Printer default or more|
|Brim |Recommended for all parts|
|Slice gap closing radius |0.001mm |

Test whether your printer can print the pieces for other open-source designs. Download and print the [leg test] file. This will only use about [5 grams of PLA][PLA filament]{qty: 1}.

The result should look like this (this has been printed with a brim):

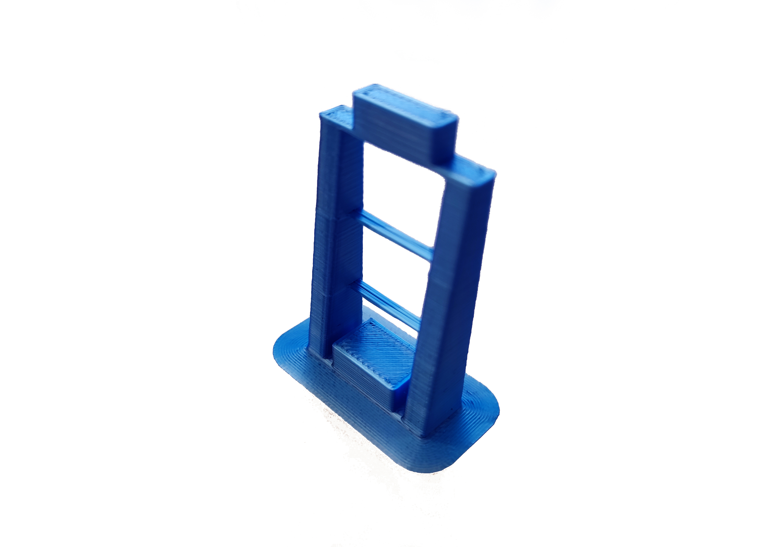
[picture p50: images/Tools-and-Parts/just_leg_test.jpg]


As a general rule, strength is more important than surface finish, so very thin layers (less than 0.15mm or so) are unlikely to result in a station that performs any better, though it may improve the appearance.

##Download and Printing {pagestep}

Now that you have tested your [3D printer][RepRap-style printer] and [filament][PLA filament] you can print the plastic parts:

You can have access to all the STLs in [**Printables**](https://www.printables.com/model/733553) or go for free to our [**Online CAD software**](https://cad.onshape.com/documents/6ad90b1b9211810137d71b1d/w/b1b0cc05a0494bf4bc912f91/e/37e5ce9fc21af2a3e931ec46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) to make your own version. You can also download them individually here:

## Clean-up of printed parts {pagestep}

>!! **Be careful when removing the brim:** To avoid injury, first remove the bulk of the brim without a knife. Remove the remaining brim with a peeling action as described below.

Carefully remove the printing brim from all parts. To remove brim:

1. Use [precision wire cutters][Precision wire cutter]{qty: 1} to remove most of the brim from the part.
2. Clean up the remaining brim with a [utility knife][Utility knife]{qty: 1, note: "Not a scalpel!"}:
    * Hold the knife in your dominant hand with 4 fingers curled around the handle, leaving your thumb free.
    * Hold the part in your other hand, as far away from the surface, to be cut as possible.
    * Support the part with the thumb of your dominant hand.
    * Place the blade on the surface to be cut, and carefully close your dominant hand, moving the blade, under control, towards your thumb.

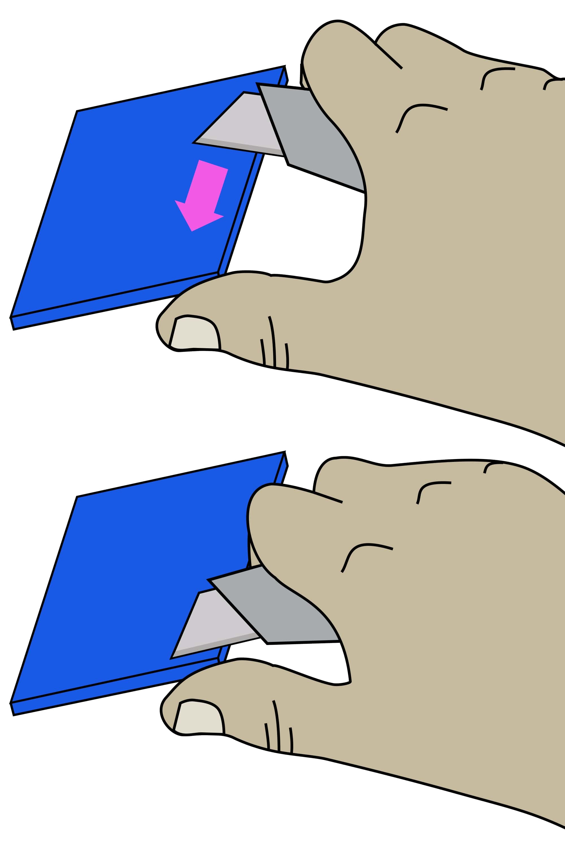
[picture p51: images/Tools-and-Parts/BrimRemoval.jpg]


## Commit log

2023-12-04 move content from spectrometer
    [bill_of_materials.xlsx]
2024-07-26 add new images and STL files
    add new images and STL files
    [Compliant_slit_insert_V2 - cap_layer.stl, Compliant_slit_insert_V2 - flex_layer1.stl, Compliant_slit_insert_V2 - flex_layer2.stl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]
2024-09-17 Update Mhl
    [Base_puzzle.stl, Compliant_slit_insert_V2-cap_layer.stl, Compliant_slit_insert_V2-flex_layer1.stl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]
2024-09-25 Update info
    [Axis-control.stp, Flexure_cylindrical_lens_holder-cyl-lens-holder-extra-tall.stl, Flexure_cylindrical_lens_holder-cyl-lens-holder-flex.stl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]
2024-09-25 Deploying to main from @ 3a75326c07c946bf20e207612d5b2877299f0859 🚀
2024-09-25 Deploying to main from @ 8f7124fc592fc4b187ea0e4eefb79747a65ef26a 🚀
2024-09-25 Deploying to main from @ bc041bd19fb8c70489514f8cbdb8e3abd53b01a6 🚀
2024-09-26 Deploying to main from @ 19c47789859e5bf6c41c779b1cc78a7b11654fa9 🚀
